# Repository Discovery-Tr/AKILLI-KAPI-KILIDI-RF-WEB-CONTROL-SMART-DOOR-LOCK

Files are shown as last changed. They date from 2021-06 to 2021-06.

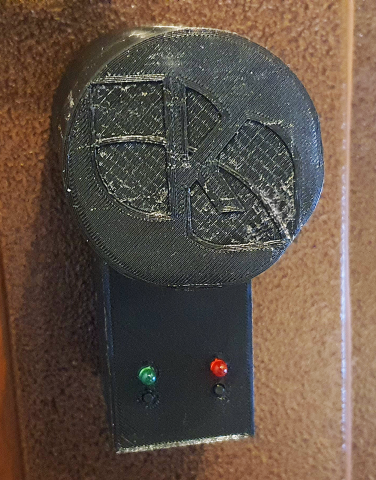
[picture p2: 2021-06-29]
Foto/Discovery-Door-Locks.png

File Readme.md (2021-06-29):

# AKILLI KAPI KİLİDİ +RF + WEB CONTROL – ( SMART DOOR LOCK )

<p align="center">
  <a href="https://www.youtube.com/watch?v=PlckOVlVY0M" target="_blank">
  
 </a>
</p>
          Merhaba,
 
          Bu yazımızda evde akıllı kapı kilidi nasıl yapılır buna değineceğiz. Piyasada hali hazırda satılan akıllı kapı kilitleri fahiş rakamlara satılmakta, ayrıca kumanda ve diğer istekler için ekstra ücretler istenmekte. Üstelik her kapıya da uyum sağlamamaktadır.

          Bu proje; ev, işyeri, her türlü kapı ve para kasaları vb. yerlere takılarak kullanılabilir. (uyarlanabilir.)  İster kumanda, ister cep telefonu veya ofisinizden bilgisayarla kontrol edebilirsiniz. Evde yokken kapınıza gelen misafire kapıyı açabilir, anahtarı unuttuğunuzda cep telefonunuzu anahtara çevirerek teknolojinin nimetinden faydalanabilirsiniz.

          Projemi yaklaşık 150 -200 tl civarı bir maliyetle hem isteğime uygun hem daha gelişmiş bir sistem kurarak sizler ile paylaşıyorum.
<p align="center">
  
  
</p>

# DEVRE ŞEMASI
<p align="center">
  
</p>

# PROJENİN İLK ÇALIŞMA AYARLARI
<p align="center">
  
  
  
</p>

     Proje rest düğmesine basıldığında da yine aşağıdaki gibi cihaz internet bağlantısı için SSD ve Şifre bilgilerini seçerek cihazın alacağı ip adresini belirlemeniz gerekmektedir.

# PROJE KODLARI
```
/*
  Name:    Discovery Door Lock.ino
  Created: 28/6/2021 23:51:11 AM
  Author:  Adem KIRMIZIYÜZ
*/

// Bütün Kütüphaneler ekleniyor
#include <DNSServer.h>
#include <ESP8266WiFi.h>         //https://github.com/esp8266/Arduino
#include <ESP8266WebServer.h>
#include <WiFiManager.h>         // https://github.com/tzapu/WiFiManager
#include <Servo.h>
#include <RCSwitch.h>
#include <EEPROM.h>
#define EEPROM_SIZE 1
RCSwitch mySwitch = RCSwitch();
WiFiServer server(80);
Servo myservo;
int buttonState;// EEPROM a kaydedeceğimiz buton durumu.

// Pinler
const int openButton = 5;  // D1
const int closeButton  = 14; // D5
const int closeLed = 12;    // D6
const int resetButton = 13; // D7
const int openLed = 15;     // D8
int buzzerPin = 16; //D0

void setup() {
  Serial.begin(115200);
  pinMode(buzzerPin, OUTPUT);
  //Pin modlarını ayarlayan method çağrılıyor
  initPinModes();

  // Wireless bağlantı ayarlarını yapan method
  initWireless();
  EEPROM.begin(EEPROM_SIZE);
  buttonState = EEPROM.read(0);// Buton durumunu EEPROM a kaydediyoruz.
  Serial.println("İlk Açılış");
  Serial.println(EEPROM.read(0));
  mySwitch.enableReceive(0);  // D3
  delay(2500);
}

void loop()
{
  buttonControl();
  htmlControl();
  rfControl();
}

void initWireless()
{
  // WiFiManager
  WiFiManager wifiManager;
  wifiManager.setSTAStaticIPConfig(IPAddress(192, 168, 1, 200), IPAddress(192, 168, 1, 1), IPAddress(255, 255, 255, 0));
  wifiManager.autoConnect("Discovery Door Lock");
  Serial.println("Connected.");
  server.begin();
}
// Pin modlarını ayarlayan method
void initPinModes()
{
  Serial.begin(115200);
  pinMode(openLed, OUTPUT);
  pinMode(closeLed, OUTPUT);
  pinMode(openButton, INPUT_PULLUP);
  pinMode(closeButton, INPUT_PULLUP);
  pinMode(resetButton, INPUT_PULLUP);
}

void htmlControl() {
  // bir clien istemci baglı olup olmadığını kontrol ediyoruz
  WiFiClient client = server.available();

  if (!client) {
    return;
  }

  // client ın bir data gondermesini bekliyoruz
  Serial.println("new client");
  while (!client.available()) {
    delay(1);
  }

  // gelen istekleri okuyoruz
  String request = client.readStringUntil('\r');
  Serial.println(request);
  client.flush();

  if ((request.indexOf("/KAPI-KAPALI") != -1 ) && (buttonState == 0))
  {
    Serial.println("Web Kapanış");
    Kapi_Kapat();

  }
  if ((request.indexOf("/KAPI-ACIK") != -1 ) && (buttonState == 1))
  {
    Serial.println("Web Açılış");
    Kapi_Ac();

  }

  // bu kısımda html kodlarını internet arayüzüne yazıdırıyoruz.
  client.println("HTTP/1.1 200 OK");
  client.println("Content-Type: text/html");
  client.println("");
  client.println("<!DOCTYPE html><html lang='tr'><head><meta charset='utf-8'><meta name='viewport' content='width=device-width, initial-scale=1,shrink-to-fit=no'>");
  client.println("<!-- Bootstrap CSS -->");
  client.println("<link rel='stylesheet' href='https://maxcdn.bootstrapcdn.com/bootstrap/4.0.0-alpha.6/css/bootstrap.min.css' integrity='sha384-rwoIResjU2yc3z8GV/NPeZWAv56rSmLldC3R/AZzGRnGxQQKnKkoFVhFQhNUwEyJ' crossorigin='anonymous'>");
  client.println("<meta http-equiv='refresh' content='3; URL=http://192.168.1.200/'></head>");
  client.println("<body>");
  client.println("<div class='container mt-2'>");
  client.println("<div class='row'>");
  client.println("<div class='col-sm-12'>");
  client.println("<div class='card'>");
  client.println("<div class='card-header'>");
  client.println("<h4>NodeMCU Door Controller</h4>");
  client.println("</div>");
  client.println("<div class='card-body'>");
  client.println("<div class='table-responsive'>");
  client.println("<thead>");
  client.println("</thead>");
  client.println("<tbody>");
  client.println("<table width='10%' height='10%' border='0' cellspacing='1' cellpadding='1'align='center'><tr>");
  client.println("<td class='align-center'>");
  if (buttonState == 0)
  {
    client.println("<a href=\"/KAPI-KAPALI\"\"><div class='d-flex align-items-center rounded float-center p-3 py-2 mb-1 bg-light rounded' style='font-size: 10em'><svg x='10' class='bi bi-unlock-fill' width='1em' height='1em' viewBox='0 0 16 16' fill='currentColor' xmlns='http://www.w3.org/2000/svg'><path d='M11 1a2 2 0 0 0-2 2v4a2 2 0 0 1 2 2v5a2 2 0 0 1-2 2H3a2 2 0 0 1-2-2V9a2 2 0 0 1 2-2h5V3a3 3 0 0 1 6 0v4a.5.5 0 0 1-1 0V3a2 2 0 0 0-2-2z'></path></svg></div></a>");
    buttonState == 1;
  }
  else if (buttonState == 1)
  {
    client.println("<a href=\"/KAPI-ACIK\"\"><div class='d-flex align-items-center rounded float-center p-3 py-2 mb-1 bg-light rounded' style='font-size: 10em'><svg class='bi bi-lock-fill' width='1em' height='1em' viewBox='0 0 16 16' fill='currentColor' xmlns='http://www.w3.org/2000/svg'><path d='M8 1a2 2 0 0 1 2 2v4H6V3a2 2 0 0 1 2-2zm3 6V3a3 3 0 0 0-6 0v4a2 2 0 0 0-2 2v5a2 2 0 0 0 2 2h6a2 2 0 0 0 2-2V9a2 2 0 0 0-2-2z'></path></svg></div></a>");
    buttonState == 0;
  }
  client.println("</td>");
  client.println("</tr>");
  client.println("</table>");
  client.println("</tbody>");
  client.println("</div>");
  client.println("</div>");
  client.println("<div class='card-footer'>");
  client.println("<div class='form-group float-left'>Adem KIRMIZIYÜZ 2021</div>");
  client.println("</div>");
  client.println("</div>");
  client.println("</body>");
  client.println("</html>");
  delay(1);
  Serial.println("Client disonnected");
  Serial.println("");
}

void buttonControl() {
  if ((digitalRead(closeButton) == HIGH) && (buttonState == 0))
  {
    Serial.println("Buton Kapanış");
    Kapi_Kapat();
  }

  if ((digitalRead(openButton) == HIGH) && (buttonState == 1))
  {
    Serial.println("Buton Açılış");
    Kapi_Ac();
  }

  if (digitalRead(resetButton) == HIGH)
  {
    Serial.println("Ayarlar Silindi");
    digitalWrite(closeLed, HIGH);
    digitalWrite(openLed, HIGH);
    ESP.eraseConfig();
    delay(3500);
    digitalWrite(closeLed, LOW);
    digitalWrite(openLed, LOW);
    EEPROM.write(0, 0);
    EEPROM.commit();
    ESP.restart();
  }
}
void rfControl()
{
  int value = mySwitch.getReceivedValue();
  if (mySwitch.available()) {

    if ((value == 14244580) && (buttonState == 1))
    {
      Serial.println("rf Açılış");

      Kapi_Ac();
      delay(1500);
    }
    if ((value == 14244577) && (buttonState == 0))
    {
      Serial.println("rf Kapanış");

      Kapi_Kapat();
      delay(1500);
    }
    else
    {
      Serial.print("İşlem Tekrarı. ");
      Serial.println(mySwitch.getReceivedValue());
    };
    mySwitch.resetAvailable();
  }
}

void Kapi_Kapat()
{
  WiFiClient client = server.available();
  digitalWrite(openLed, HIGH);
  for (int i = 0; i < 2; i++) // Buzzer için 2 defa dönülüyor
  {
    digitalWrite(buzzerPin, HIGH); // Buzzer açılıyor
    delay(200); // 0.2 sn bekleniyor
    digitalWrite(buzzerPin, LOW); // Buzzer kapatılıyor
    delay(200); // 0.2 sn bekleniyor
  }
  Serial.println(EEPROM.read(0));
  myservo.attach(4);//D2
  myservo.write(100);
  client.print("POST /KAPI-KAPALI/ HTTP/1.1");
  delay(3500);
  client.print("POST / HTTP/1.1");
  myservo.detach();
  buttonState = 1;
  EEPROM.write(0, buttonState);
  EEPROM.commit();
  digitalWrite(openLed, LOW);
}

void Kapi_Ac()
{
  digitalWrite(closeLed, HIGH);
  WiFiClient client = server.available();
  digitalWrite(buzzerPin, HIGH);
  delay(200);
  digitalWrite(buzzerPin, LOW);
  Serial.println(EEPROM.read(0));
  myservo.attach(4);//D2
  myservo.write(80);
  client.print("POST /KAPI-ACIK/ HTTP/1.1");
  delay(5000);
  myservo.write(91 );
  delay(2000);
  myservo.attach(4);//D2
  myservo.write(100);
  delay(60);
  myservo.detach();
  client.print("POST / HTTP/1.1");
  buttonState = 0;
  EEPROM.write(0, buttonState);
  EEPROM.commit();
  digitalWrite(closeLed, LOW);
}
``` 

# MALZEMELER
# Motor:
MG996R Yüksek Torklu Servo Motor 180 Derece Metal Dişli x1
<p align="left">
  
</p>

Not: Servo içerisindeki potansiyometre sökülerek yerine 2 adet 10k direnç bağlanmalıdır. İki köşeye 10k dirençler bağlanarak orta uçta birleştirilecektir. Ayrıca servo motorun tam tur yapmasını engelleyen çentik kesilmelidir.

# Micro Controller (NodeMCU):
NodeMCU LoLin ESP8266 Geliştirme Kartı x1
<p align="left">
  
</p>

# RF Alıcı Verici:
433 MHz RF Kablosuz Alıcı(Reciver) X1

433 MHz 4 Kanal RF Elcik Kumanda X1
<p align="left">
  
  
</p>

# Diğer Elemanlar:
470 Ohm Direnç x5
<p align="left">
  
</p>

Push Button x3
<p align="left">
  
</p>

Piezo Buzzer x1
<p align="left">
  
</p>

Bir miktar kablo
<p align="left">
  
</p>

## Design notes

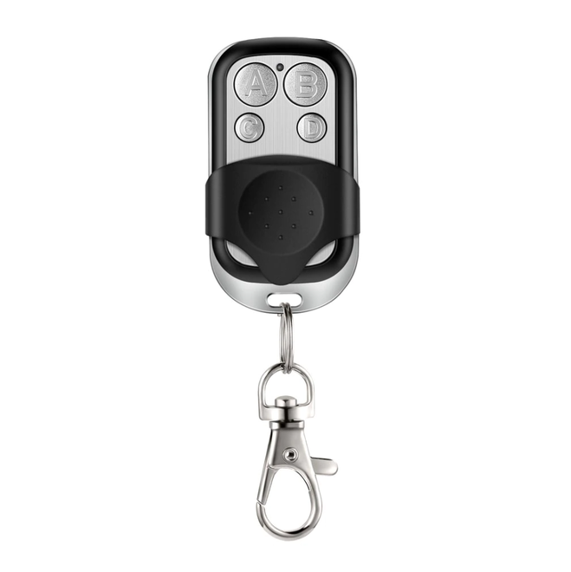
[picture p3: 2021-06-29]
Foto/433-mhz-4-kanal-rf-elcik-kumanda-28289-84-O.png

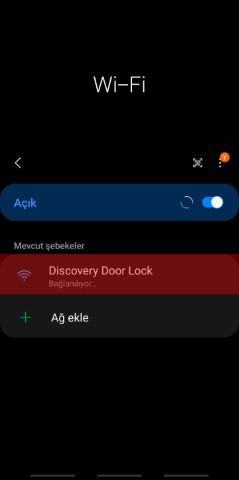
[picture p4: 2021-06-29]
Foto/Discovery-Door-locks (1) (Küçük).jpg

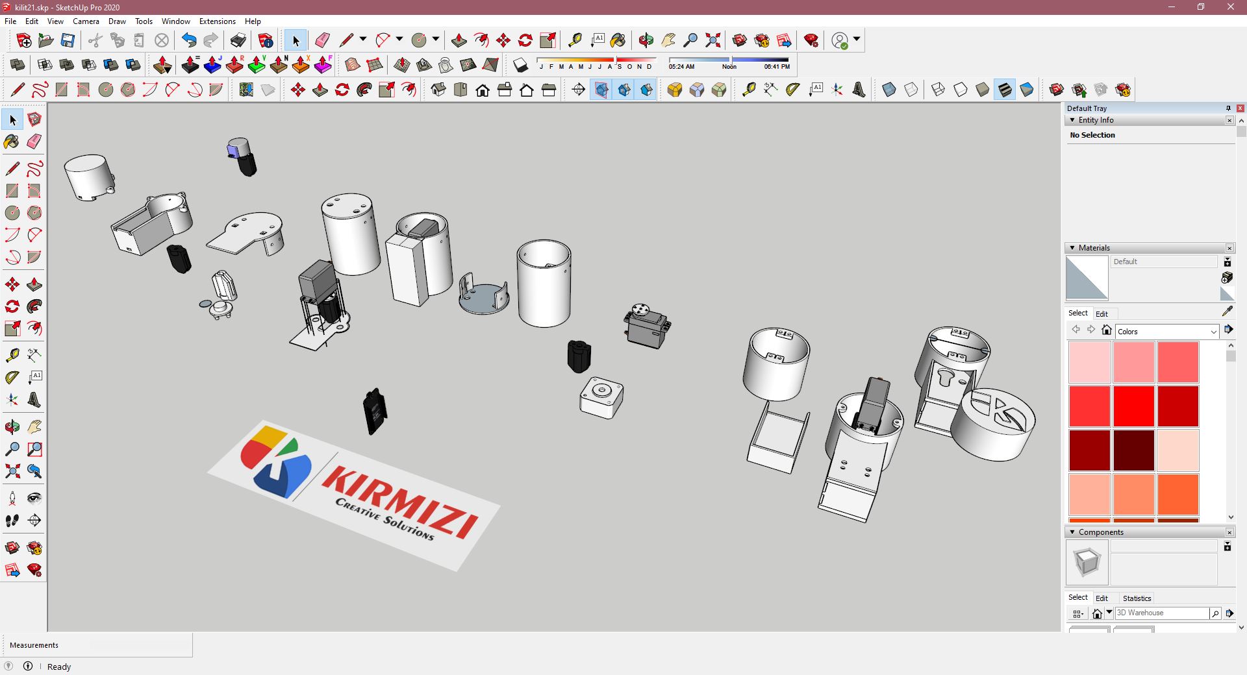
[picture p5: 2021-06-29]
Foto/3D Aşamalar.JPG

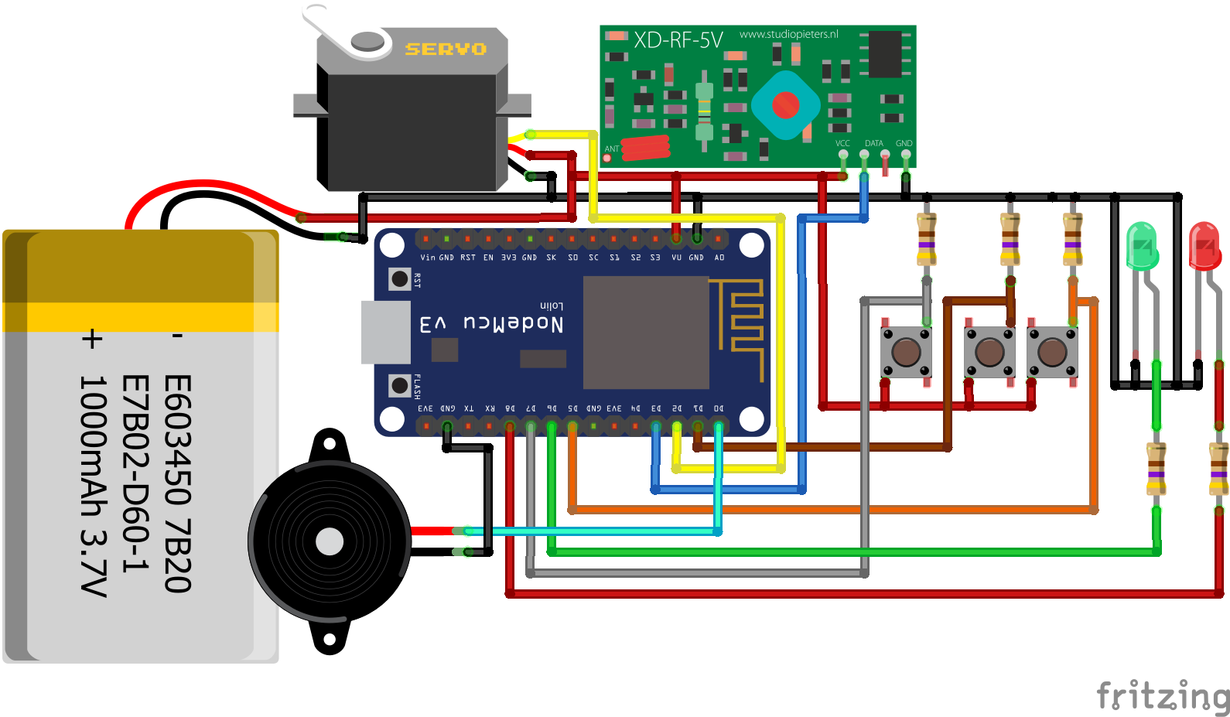
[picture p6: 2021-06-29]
Çizim/Akilli-kapi-kilidi-devre-semasi.png

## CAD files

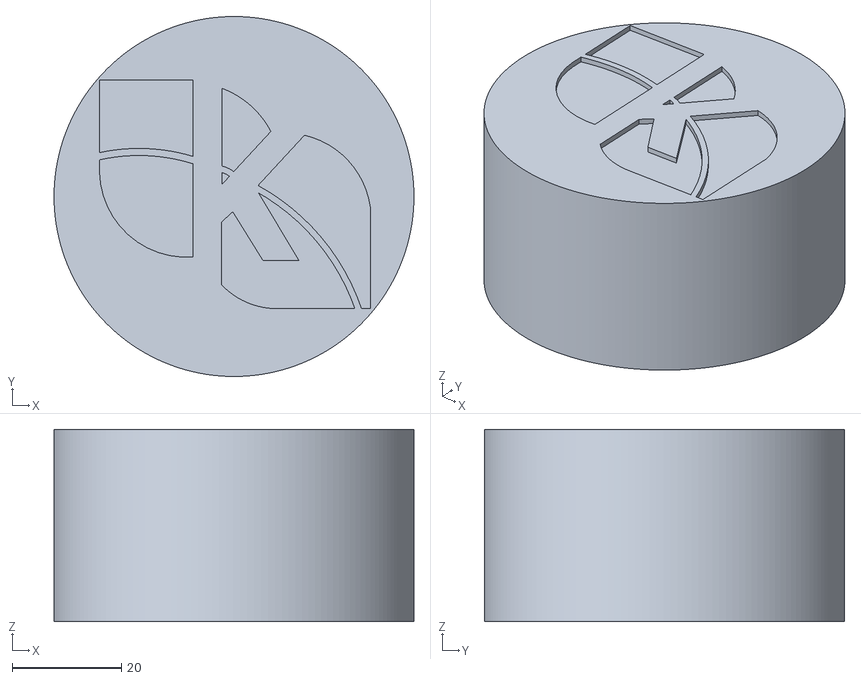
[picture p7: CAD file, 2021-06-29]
3D/kapak.stl
66.0 x 66.0 x 35.2

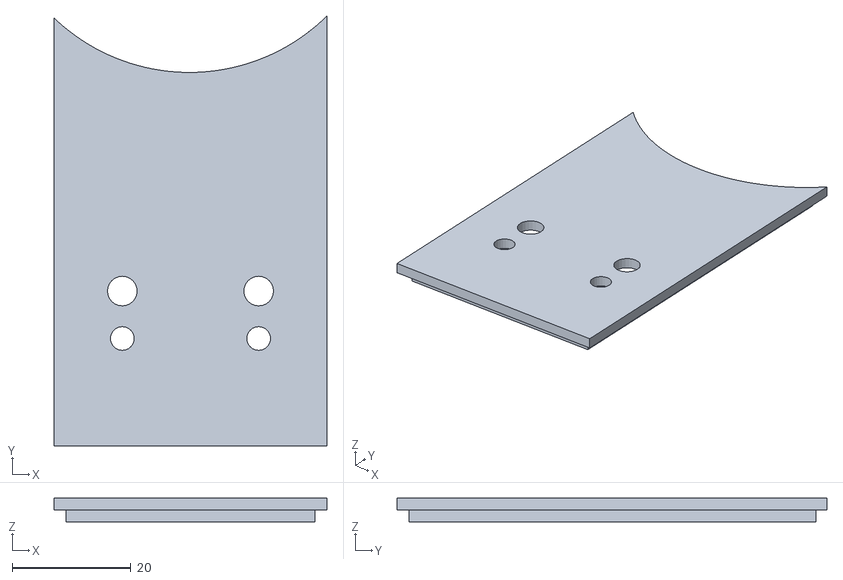
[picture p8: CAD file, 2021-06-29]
3D/kasa1.stl
46.0 x 72.5 x 4.00

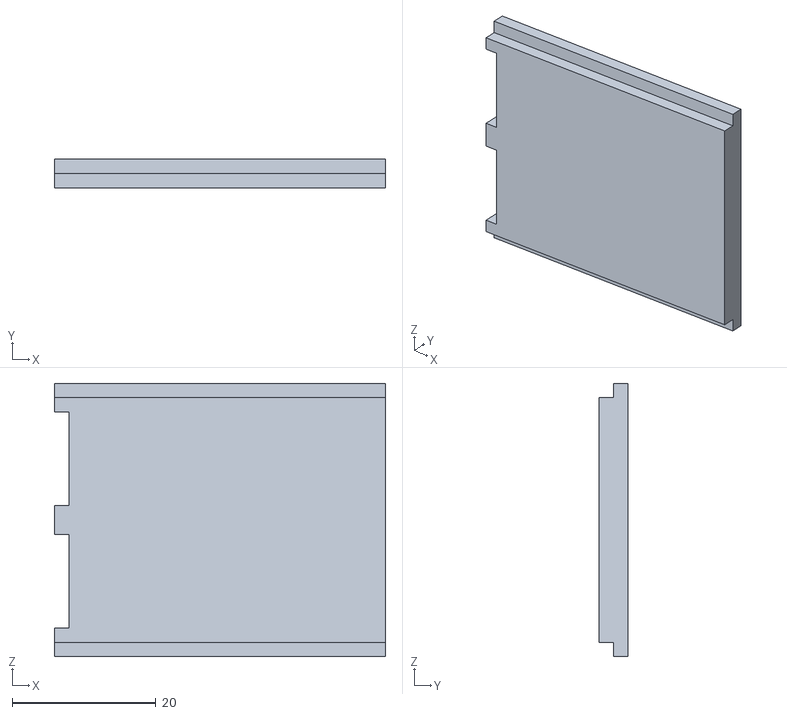
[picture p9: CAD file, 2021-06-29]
3D/kapak3.stl
46.0 x 4.00 x 38.0

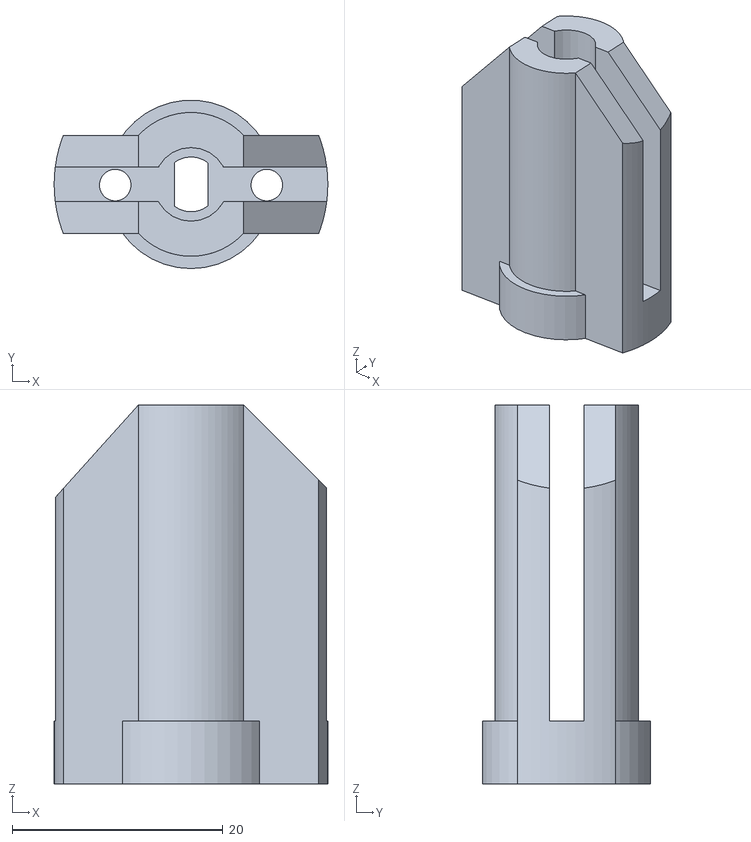
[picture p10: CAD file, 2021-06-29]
3D/anahtar1.stl
26.0 x 16.0 x 36.0

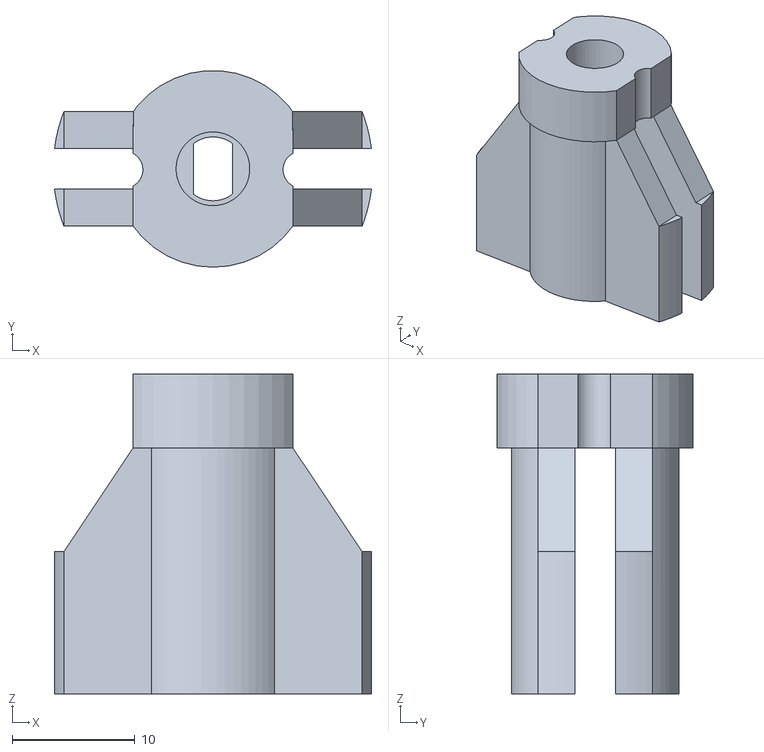
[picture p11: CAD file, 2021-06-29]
3D/anahtar2.stl
25.8 x 16.0 x 26.0

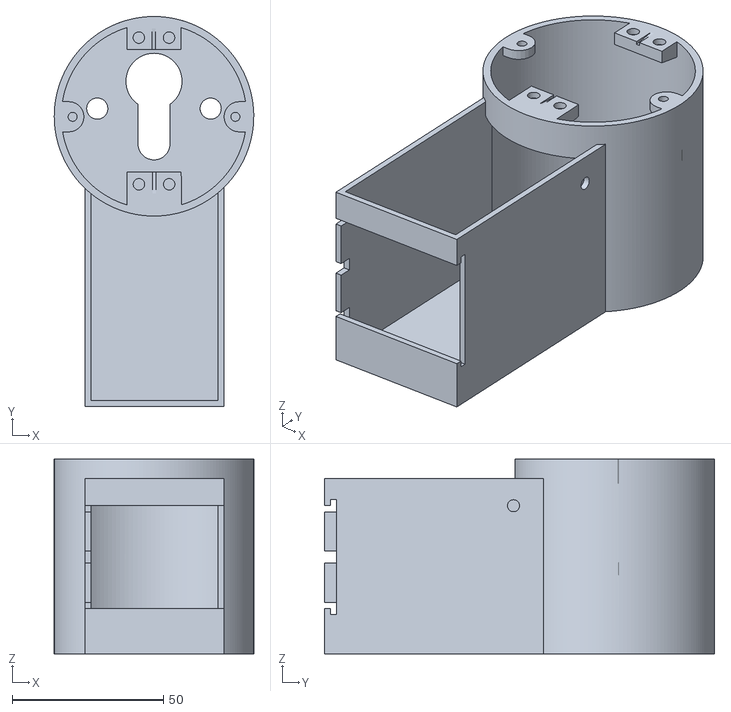
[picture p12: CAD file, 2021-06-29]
3D/kasa.stl
66.0 x 129.0 x 64.4

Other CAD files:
3D/anahtar.stl
3D/anahtar0.stl
